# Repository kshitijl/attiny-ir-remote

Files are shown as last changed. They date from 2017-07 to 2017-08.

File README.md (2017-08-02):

## First attempt: phototransistor

This didn't work.

## Second attempt: TSOP sensor and a constant-on signal

The sensor filtered me out.

## Debug traces

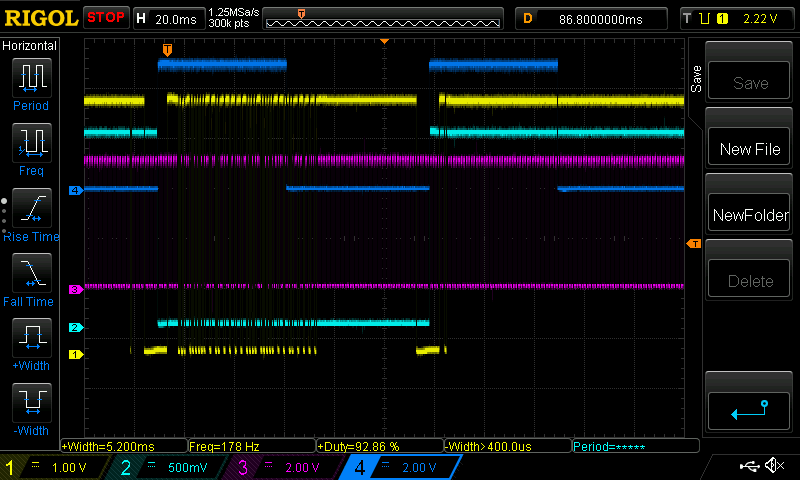
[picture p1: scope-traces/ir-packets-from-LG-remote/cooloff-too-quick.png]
Cooloff too quick Title


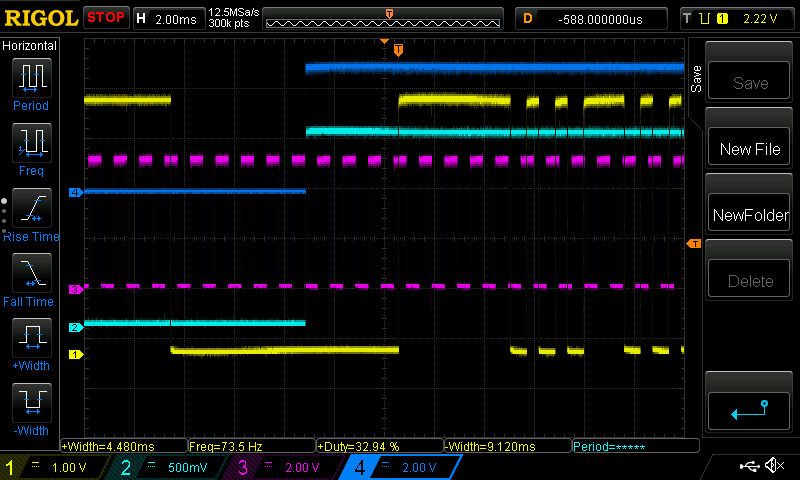
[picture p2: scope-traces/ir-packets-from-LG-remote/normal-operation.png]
Normal operation a


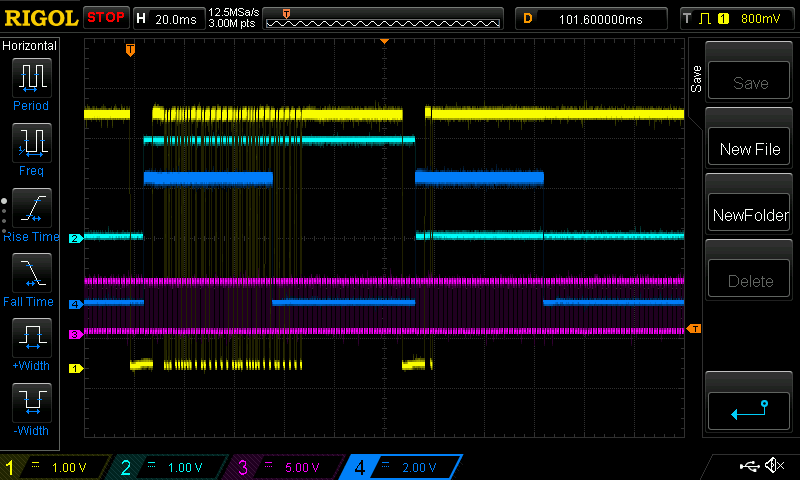
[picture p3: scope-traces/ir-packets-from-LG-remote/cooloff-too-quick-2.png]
Cooloff too quick b


## Calculating the resistance in series with IR LED

TSAL7400 http://www.mouser.com/catalog/specsheets/tsal7400.pdf
max current: 100mA
forward voltage @ 100mA: 1.35V

During development, I'm using a 5V adapter that I found in my bag of
old junk. I cut off the connector and soldered two jumpers.

V_cc: 5v
So R = (5 - 1.35)/100mA = 36.5ohm

47ohm is the closest value >= 36.5 (to give a safety margin).

For 2 LED's in series,
R = (5 - 2*1.35)/100mA = 23ohm
22 ohm is close enough

With a 3V CR1220,	
R = (3-1.35)/100mA = 16.5ohm
22ohm is the closest I have >= 16.5 ohm

With 2 LED's,
R = (3-2*1.35)/100mA = 3ohm
4.7 ohm is the closest I have.

## Receiving

The lengths of pulses recorded are the same, no matter how much I
change my timescale! I felt trapped in a bizarro fractal universe,
where the remote was broadcasting the same signal at any level of
detail I cared to look at.

More likely, something was wrong with my timer setup code. Eventually
I took a peek at the IR Arduino library's setup code, and noticed that
he set every setup register directly to its value, even `TCNT2`,
whereas I had just assumed that the bootloader (or some other friendly
harness code that runs before mine) would set all registers to 0.

Nope. This isn't Linux any more. Nobody will clean up before you
arrive, and my carelessness was brutally punished with 2 hours of
bizarro fractal debugging. Lesson learned.

## Power struggles

Now that I have an ugly but functional solution I need to think about
how I'm going to power the final version. The receiver sits near the
speakers so it can be plugged into the wall with an AC adapter I
scavenge. That's good because it powers a servo and listens constantly
for incoming signals, both of which cost power.

The remote, on the other hand, obviously needs to carry its own. My
choices are coin battery, AA or AAA batteries. If I really can't get
my shit together then I suppose one of those huge 9v batteries is an
option, but that would be pretty embarrassing.

The `ATTiny85` datasheet has summary data about power consumption:

ATtiny85 
Operating Voltage
– 1.8 - 5.5V for ATtiny25V/45V/85V
– 2.7 - 5.5V for ATtiny25/45/85
• Speed Grade
– ATtiny25V/45V/85V: 0 – 4 MHz @ 1.8 - 5.5V, 0 - 10 MHz @ 2.7 - 5.5V
– ATtiny25/45/85: 0 – 10 MHz @ 2.7 - 5.5V, 0 - 20 MHz @ 4.5 - 5.5V
• Industrial Temperature Range
• Low Power Consumption
– Active Mode:
• 1 MHz, 1.8V: 300 µA
– Power-down Mode:
• 0.1 µA at 1.8V

Crap! Looks like I should have ordered the low-power `ATTiny85V`
variant. Assuming I get one of those, I see two modes, and boy are
they different!

With a CR1220 coin battery running at 3V (measured 3.2V) and a
capacity of 40mAh,
=> 40mAh/100mA = 0.4h
= 1440s of continuous LED discharge (ignoring ATtiny)

When I tried using the coin battery in real life, the range was worse
than what I got using a 5v AC adapter. One obvious reason for this is
that the LED is running with lower current -- the resistor in series
is calibrated to deliver 100mA (less safety margin) at 5v.

But another possible reason for bad range could be that the internal
clock runs slightly off from the measured 8.02MHz at this different
voltage. I will have to measure it and adjust.

AAA battery 1.5V
Typical capacity: 1000mAh

TSOP 1738 pin order: signal ground vcc from front (facing me)

/*
In [1]: 8000000.0/(2*38000)
Out[1]: 105.26315789473684

In [2]: X = 2*39060 * 105

In [3]: X
Out[3]: 8202600

In [4]: 8202600./(2*38000)
Out[4]: 107.92894736842105

Chip was running at 8.2026Mhz, so 108-1 = 107 gave a perfect 38KHz
modulated signal.
 */

On power down mode at 5V, I measured a current of 0.5uA (for the whole
circuit). That gives me 80,000 hours with the tiny CR220 battery,
assuming current consumption is the same at a lower voltage
(unlikely).

While a button is pressed, my multimeter reports 15mA. That the value
is lower than 100mA makes sense: just like a 200mA current at a 50%
duty cycle is reported as 100mA by this meter, the same peak current
over the much smaller duty cycle in sending bits (and the timeouts
between bytes) averages out to a lot less. We calculated 1440s of
continuous discharge. Estimating a duty cycle of 15%, we get 9600s of
discharge. Since power consumption in power down mode is a tiny
fraction of this number we can assume that the entire battery will be
consumed due to discharge. Assuming a button is held down for about 3
seconds each time volume is adjusted, we get something like 3200
volume adjustments from this tiny battery.

Is that great or is that terrible? I am such a beginner that I don't
know what is considered awful performance. On a desktop, for example,
doing millions of operations per second (megaflops) of computation
sounds impressive but is actually laughably pitiful. It is several
orders of magnitude away from good. So 3200 button presses sounds
pretty good to me but maybe it's awful.

## Soldering and bringup

## Clash of the timers

When I hooked up the now-working receiver code to the actual servo on
the speaker, the servo behaved very erratically. Had I damaged the
motor with all that working of instamorph moulding? After a lot of
debugging, I tracked the issue down to a clash of the timer used by
the Servo library, with the timer I was using for receiving.

This surprised me and I need to follow up on it. I was using timer 2,
while the Servo library uses timer 1. This is quite clear from
documentation, from the existence of a timer2 Servo library separate
from the default, from the way the compiler complains if you try to
define a timer1 interrupt handler, and forums. But I had a legitimate
test case where changing Timer2 registers messed up whether I could
make the servo turn.

The best way to figure it out is a combination of writing my own servo
library, reading the atmega328 datasheet, and reading the Servo
library source. But an even bigger consideration for me here is that
my final receiver will be an ATtiny85, not an ATmega, so if I am going
to do a deep dive on timers and PWM for any microcontroller it ought
to be the ATtiny.

### Answer: It's because I disable and enable interrupts

	ref: Using NeoPixels and Servos Together by Phillip Burgess

I use an interrupt handler running on a timer to measure intervals
between state-changes in the input from the TSOP sensor. When a
message in ready to be processed, I turn interrupts off so that if a
new message comes in, it doesn't overwrite the current one before
we're done processing it.

However, the Arduino Servo library uses timer interrupts, not a PWM
mode, so when interrupts are turned off, this throws off the waveform
being sent to ther sevo, resulting in the jittering I'm seeing.

Solution: there are two solutions here. First, I could use a PWM mode
to control the servo.
					 
Second, don't disable interrupts; instead, use a different way to lock
access to the current message. I can think of a couple ways to do
that.

1. A variable that says whether the current message is writable. This
is what I already have: if we are in STATE_MESSAGE_READY, the timer
interrupt exits immediately. But there might be a data race here.

2. I could specifically turn off timer 2 before processing the
message.

3. I could use a small circular queue buffer for messages.

## PWM frequency is off by 25% from my calculations

### Is the internal 1MHz clock really 1MHz?

Yes -- using CTC toggle mode with no prescaling and OCR0A=0, I get a
505KHz square wave. The pulse widths are pretty much spot on at 1
microsecond. Close enough.

### Can I get a 50Hz square wave in CTC mode?

Yes if I write it as OCR0A = 39.
No if I write it as OCR0A = (F_CPU / 256000) * 20 / 2;

Got it! It's a truncation bug. Rearranging like this:

OCR0A = ((F_CPU / 1000) * 20 / 256) / 2;

fixes the problem.

## Why do I love the ATTiny so much?

I am a beginner so my opinion is worthless. But I just find the ATtiny
so charming! 

## Auto syncing clocks between sender and receiver

Moving to a different timer meant I had to measure a bunch of
constants and change them in my program. That's because the lengths of
pulses sent by the ATtiny are shorter or longer depending on your
timer frequency, and there will be errors if you just assume perfectly
precise clock speeds.

This got me thinking that real implementations must sync clock
intervals as unknown hardware gets added to the network.

In preparation for something like that, I refactored my hardcoded
checks into this:

```
bool is_close_to(int value, int target) {
  return abs(value-target) < target/5;
}

const int transmitter_millisecond = 125;
const int length_of_one = 5 * transmitter_millisecond;
const int length_of_zero 250;
```

Now, when the time comes to do auto syncing of clocks, that constant
`transmitter_millisecond` will become a variable, and `length_of_one`
and `length_of_zero` will be functions that depend on the current
value of `transmitter_millisecond`.

How will the auto-syncing work? When message receipts are going
successfully (vague), we will adjust the value of
`transmitter_millisecond` so that the lengths of `one` and `zero`
pulses that we are actually seeing match what `length_of_one` and
`length_of_zero` return.

## Why did using a raw photodiode fail?

There are several things the TSOP+TSAL combo is doing better than my
first attempt. First and most fundamentally, I now believe that the
raw signal from a photodiode probably goes through a lot of gain. I
probably _was_ getting a signal, just very weak.

But gain leads to noise. They use two ways to reduce the noise. First,
there's a physical covering on the sensor that filters away things
that aren't in a certain band of wavelengths (within the infrared
region). Second, they filter away everything that isn't 38KHz.

Finally, the LED itself is a beast. It can deal with 100mA
continuously, and 200mA when flashing 38KHz with a duty cycle of 50%.

It will be very interesting to apply these lessons by trying to build
a sensor in the same style that can achieve signalling across a room. 

## How fast can we respond to input?

### Using a tight loop in the main thread

Around 9 microseconds (9 instructions) to read an input pin and copy
its state to an output pin.

### Using a timer overflow interrupt with no prescaler

About 50 microseconds in my experiments, although this will vary and
can be as bad as 255 microseconds, because the counter goes up to 255
before overflowing and causing the interrupt.

## Notes on type checking

Using WGM02 with TCCR0A should be a type error.

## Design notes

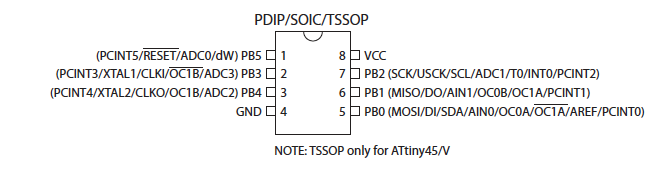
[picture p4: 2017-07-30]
pinout.png

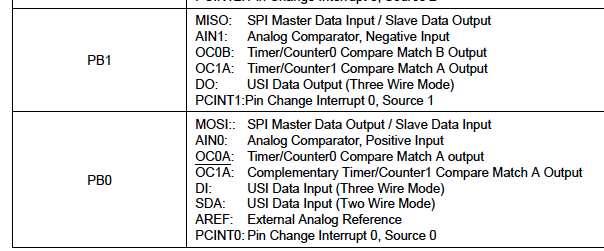
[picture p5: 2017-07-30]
pwm-pins.png

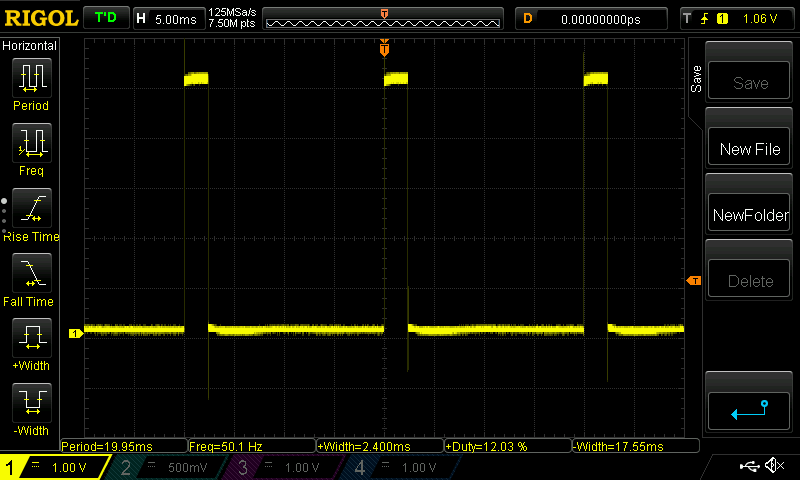
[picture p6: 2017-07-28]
scope-traces/pwm-for-servo/angle-180.png

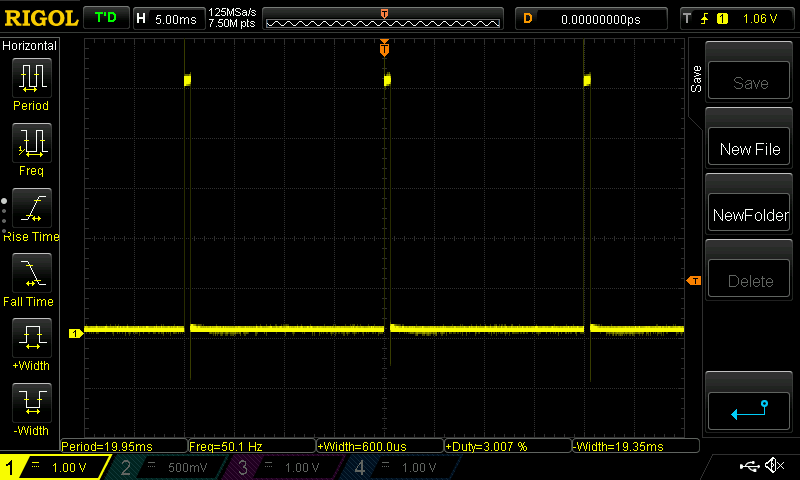
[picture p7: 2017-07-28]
scope-traces/pwm-for-servo/NewFile2.png

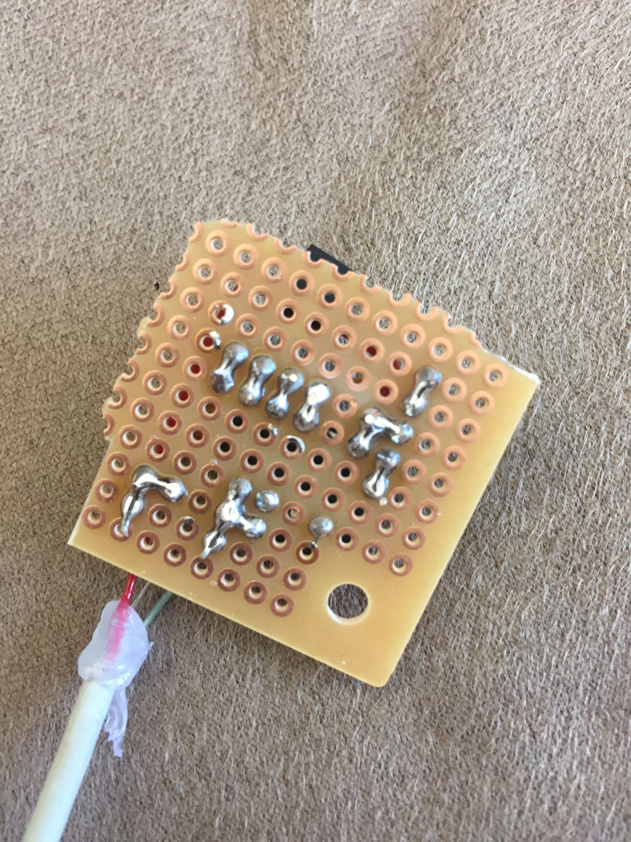
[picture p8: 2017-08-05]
progress-pics/2017-08-05 16.20.38.jpg

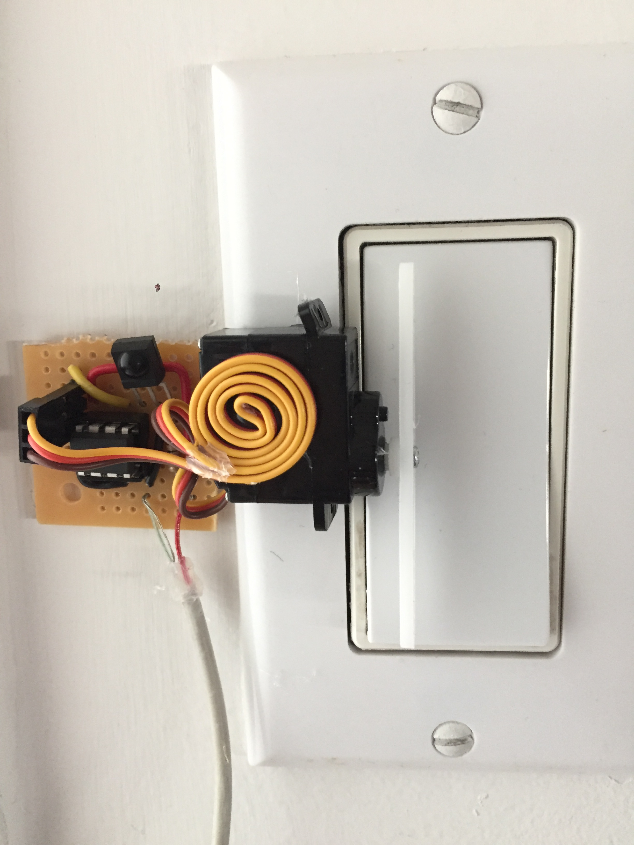
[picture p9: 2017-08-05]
progress-pics/2017-08-05 16.40.07.jpg

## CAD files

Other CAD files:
scope-traces/ir-packets-from-LG-remote/msg2.stp
scope-traces/ir-packets-from-LG-remote/ir.stp

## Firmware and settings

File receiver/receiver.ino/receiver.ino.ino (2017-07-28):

#include <avr/io.h>
#include <avr/interrupt.h>
#include <Servo.h>

// #define DEBUG_SERIAL 1

Servo knob_servo;

const int timeout = 1500;

void setup() {
  #ifdef DEBUG_SERIAL
  Serial.begin(9600);
  #endif
  
  
  pinMode(2, INPUT);
  // Set the Timer Mode to CTC
    TCCR0A = (1 << WGM01);

    // Set the value that you want to count to
    OCR0A = 1;

    TIMSK0 = (1 << OCIE0A);    //Set the ISR COMPA vect

    sei();         //enable interrupts


    TCCR0B = (1 << CS01) | (1 << CS00);
    // set prescaler to 256 and start the timer

    sei();
    // enable interrupts

     knob_servo.attach(7);

}

enum { STATE_IDLE, STATE_MARK, STATE_SPACE, STATE_MESSAGE_READY };
volatile int current_state = STATE_IDLE;

int read_sensor() {
  // https://www.arduino.cc/en/Reference/PortManipulation
  int val = PIND & _BV(PB2); //digitalRead(2);
  if(val == LOW)
      return HIGH;
   return LOW;
}

const int MAX_MESSAGE_LENGTH = 50;

volatile int counter = 0;
volatile int message[MAX_MESSAGE_LENGTH];
volatile int message_index = 0;

int volume = 5;
bool muted = false;

void volume_up() {
  #ifdef DEBUG_SERIAL
  Serial.println("Volume up");
  #endif
  volume = min(150, volume+1);
 //volume = 100;
}

void volume_down() {
  #ifdef DEBUG_SERIAL
  Serial.println("Volume down");
  #endif
  volume = max(5, volume-1);
}

void toggle_mute() {
    muted = !muted;
}

void write_knob() {
  if(muted)
      knob_servo.write(1);
   else
       knob_servo.write(volume);
}

enum { MSG_VOLUME_UP = 25, MSG_VOLUME_DOWN = 98,
       MSG_TOGGLE_MUTE = 121 };

bool is_close_to(int value, int target) {
  return abs(value-target) < target/5;
}

const int transmitter_millisecond = 125;
const int length_of_one = 5 * transmitter_millisecond;
const int length_of_zero 250;

void interpret_message() {
  int message_length = message_index;
    int decoded = 0;

    #ifdef DEBUG_SERIAL 
      Serial.print("Message length:");
      Serial.println(message_length);
      #endif

    for(int ii = 0; ii < message_length; ii += 2) {
      int ll = message[ii];
      int bit = 0;
      #ifdef DEBUG_SERIAL 
      Serial.print(ll);
      Serial.print(" ");
      #endif
      
      if(IS_CLOSE_TO(ll, LENGTH_OF_ONE)) 
          bit = 1;
       if(IS_CLOSE_TO(ll, LENGTH_OF_ZERO))
          bit = 0;

       decoded += (bit << ii/2);
    }

      #ifdef DEBUG_SERIAL 
      Serial.println("\n");
      Serial.print(decoded);
      Serial.flush();
      #endif    

    if(decoded == MSG_VOLUME_UP) {
      volume_up();
    }
  
    if(decoded == MSG_VOLUME_DOWN)
      volume_down();

    if(decoded == MSG_TOGGLE_MUTE)
      toggle_mute();
}

void loop() {
    if(current_state == STATE_MESSAGE_READY) {
    cli();
    interpret_message();
    write_knob();
    current_state = STATE_IDLE;
    sei();
  }
    
  write_knob();

}


ISR (TIMER0_COMPA_vect)  // timer0 overflow interrupt
{
  int value = read_sensor();

  if(current_state == STATE_MESSAGE_READY)
      return;

  if(message_index >= MAX_MESSAGE_LENGTH)
      message_index = 0;
  
  if(value == HIGH) {
      if(current_state == STATE_IDLE) {
          current_state = STATE_MARK;
          counter = 0;
          message_index = 0;
      }
      else if(current_state == STATE_MARK)
          counter++;
      else if(current_state == STATE_SPACE) {
        current_state = STATE_MARK;
        message[message_index++] = counter;
        counter = 0;
      }
  }
  else {
    if(current_state == STATE_MARK) {
      current_state = STATE_SPACE;
      message[message_index++] = counter;
      counter = 0;
    }
    else if(current_state == STATE_SPACE)
      counter++;
    if(counter > timeout and current_state != STATE_IDLE) {
      current_state = STATE_MESSAGE_READY;
    }
  }
}

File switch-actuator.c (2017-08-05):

#define F_CPU           1000000UL

#include "attiny85-util.h"

#define tick_size_in_us 512

// Toggles output state every time a pulse > 5ms is detected.
// Turns motor

const uint8_t input_pin  = PIN0; // pin 5
const uint8_t pwm_output_pin = PIN1; // pin 6
const uint8_t debug_out_pin = DDB3; // pin 2

// Number of timer overflows to block receipt of further messages.
// A second or 0.5 of cooloff seems appropriate.
const uint32_t cooloff_time = 500000 / tick_size_in_us;

enum receiver_state {
  STATE_IDLE,
  STATE_COOLING_OFF
};
typedef enum receiver_state receiver_state_t;

enum actuator_state {
  STATE_IDLE_ON,    // toggle comes in -> TURNING_OFF
  STATE_IDLE_OFF,   // toggle comes in -> TURNING_ON
  STATE_TURNING_ON, // ignore toggles. use timer to gradually turn on, then -> FROM_ON_TO_IDLE
  STATE_FROM_ON_TO_IDLE, // use timer to gradually go back to central position, then -> IDLE_ON
  STATE_TURNING_OFF,
  STATE_FROM_OFF_TO_IDLE  
};
typedef enum actuator_state actuator_state_t;

volatile uint8_t  pulse_length_so_far;
volatile uint32_t cooloff_counter;
volatile receiver_state_t current_receiver_state;
volatile actuator_state_t current_actuator_state;

/* Actual min and max are 2 and 8 */
const uint8_t duty_min = 4, duty_max = 6, duty_idle = 5;
int8_t movement_direction = 1;

void initialize_state() {
  pulse_length_so_far = 0;
  cooloff_counter     = 0;
  
  current_receiver_state = STATE_IDLE;
  current_actuator_state = STATE_IDLE_OFF;
}

void initialize_hardware() {
  clear_timers_and_io_pins();
  set_as_output_pin(pwm_output_pin);
  set_as_output_pin(debug_out_pin);
}

void configure_timer1_interrupt() {
  enable_timer1_overflow_interrupt();
  start_timer1(TIMER1_PRESCALER_2);

  sei();
}

void configure_pwm() {
  // In mode 7, TCNT0 counts from 0 to OCR0A for a complete PWM cycle.
  // We want the time period to be 20ms.
  // OCR0A * tick_period = 20ms
  // OCR0A = 20ms/tick_period_in_ms = 20ms * tick_frequency_in_1000Hz
  // OCR0A = 20ms * (1000 KHz / 256)
  // OCR0A = 20 * F_CPU / 256000

  put_timer0_in_fast_pwm_mode_with_top(TIMER0_PRESCALER_256,
                                       TIMER0_PIN1_ACTUALLY_6,
                                       20 * F_CPU / 256000);
}

void set_duty_ticks(uint8_t duty_in_ticks_not_percent) {
  if(duty_in_ticks_not_percent <= duty_max and
     duty_in_ticks_not_percent >= duty_min)
    OCR0B = duty_in_ticks_not_percent;
}

uint8_t get_current_duty() {
  return OCR0B;
}

void initialize_actuator() {
  set_duty_ticks(duty_idle);
}

int main (void) {
  initialize_hardware();
  initialize_state();

  configure_timer1_interrupt();
  configure_pwm();

  initialize_actuator();

  while (1) {
  }
 
  return 0;
}

uint32_t actuator_timer;
const uint32_t time_to_turn_horn = 300000/tick_size_in_us;

void set_actuator_timer() {
  actuator_timer = time_to_turn_horn;
}

void send_pulse_to_actuator_state_machine() {
  if(current_actuator_state == STATE_IDLE_ON) {
    set_duty_ticks(get_current_duty() - 1);
    current_actuator_state = STATE_TURNING_OFF;
    set_actuator_timer();
  }
  else if(current_actuator_state == STATE_IDLE_OFF) {
    set_duty_ticks(get_current_duty() + 1);
    current_actuator_state = STATE_TURNING_ON;
    set_actuator_timer();
  }
  // Ignore input pulses while in other states.
}

void do_pulse_received_action() {
  send_pulse_to_actuator_state_machine();
}

void enter_cooloff_state() {
  current_receiver_state = STATE_COOLING_OFF;
  cooloff_counter = cooloff_time;
}

void exit_cooloff_state() {
  current_receiver_state = STATE_IDLE;
  cooloff_counter = 0;
}

/*
  5ms = 5000us = 5000 cycles at 1MHz.
  
  With a prescaler of 2, an interrupt happens every 512 microseconds.
  5ms/512us = 9.7 interrupts to count out 5ms.
*/

const uint8_t accept_threshold = 10;

void advance_receiver_state(uint8_t sensor_value) {
  if(current_receiver_state == STATE_COOLING_OFF) {
    if(cooloff_counter == 0) {
      exit_cooloff_state();
    }
    else
      cooloff_counter--;
  }
  else if (current_receiver_state == STATE_IDLE) {
  
    if(sensor_value) {
      if(pulse_length_so_far >= accept_threshold) {
        do_pulse_received_action();

        pulse_length_so_far = 0;

        enter_cooloff_state();      
      } else
        pulse_length_so_far++;
    }
    else {
      pulse_length_so_far = 0;
    }
  }  
}

void advance_actuator_state() {
  /* If we are in an idle state, do nothing. */
  if(current_actuator_state == STATE_IDLE_ON or
     current_actuator_state == STATE_IDLE_OFF)
    return;

  /* If there is time left on the actuator timer, do nothing other
   * than decrementing that counter.
   */
  if(actuator_timer > 0)
    actuator_timer--;

  /* The timer has gone off. Transition to the next state. */
  else {
    if(current_actuator_state == STATE_TURNING_ON) {
      set_actuator_timer();

      if(get_current_duty() != duty_max) {
        set_duty_ticks(get_current_duty() + 1);
      } else {
        set_duty_ticks(duty_idle);
        current_actuator_state = STATE_FROM_ON_TO_IDLE;
      }
    }
    else if(current_actuator_state == STATE_TURNING_OFF) {
      set_actuator_timer();

      if(get_current_duty() != duty_min) {
        set_duty_ticks(get_current_duty() - 1);
      } else {
        set_duty_ticks(duty_idle);
        current_actuator_state = STATE_FROM_OFF_TO_IDLE;
      }      
    }
    else if(current_actuator_state == STATE_FROM_OFF_TO_IDLE) {
      current_actuator_state = STATE_IDLE_OFF;
    }
    else if(current_actuator_state == STATE_FROM_ON_TO_IDLE) {
      current_actuator_state = STATE_IDLE_ON;
    }
  }     
}

ISR (TIMER1_OVF_vect) {
  toggle_pin(debug_out_pin);
  advance_receiver_state(!(read_pin(input_pin)));
  advance_actuator_state();
}


void old_motor_code() {
  const int lower = 20, upper = 100;
  
  while (1) {
    for(int angle = lower; angle < upper; ++angle) {
      //OCR0B = angle_to_OCR0B(angle);
      _delay_ms(10);
    }
    //_delay_ms(1000);
    for(int angle = upper; angle > lower; --angle) {
      //OCR0B = angle_to_OCR0B(angle);
      _delay_ms(10);
    }
  }
}

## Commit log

2016-12-06 First cut of transmitter
2016-12-07 Note on CR1220 battery
2016-12-09 Continuous button press sends signal continuously.
2016-12-09 Some reorganization before power-down mode
2016-12-09 Stay in power down mode until a button is pressed.
2016-12-10 Add notes on power down; make it the README
2016-12-11 Notes on timer troubles
2016-12-11 Use timer 0; for some reason, timer 2 interferes with Servo operation
    [receiver.ino.ino]
